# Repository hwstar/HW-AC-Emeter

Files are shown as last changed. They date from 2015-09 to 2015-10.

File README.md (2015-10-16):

**HW-AC-Emeter**
==========
This is the hardware implementation for my Atmel 90E24 power line monitor project. The Atmel 90E24 is a complete energy management solution on a chip. It allows
voltage, current, true power, apparent power, reactive power, power factor, phase angle, and line frequency to be accurately measured. Additionally it can measure
energy and with firmware, you can convert the energy pulses into kilowatt hours.

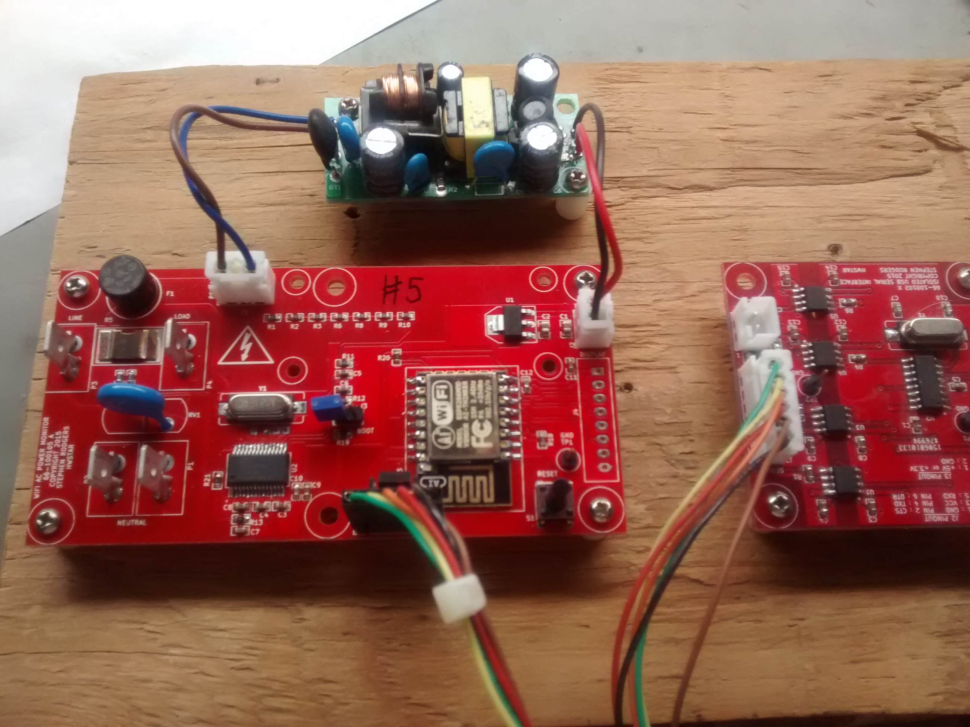
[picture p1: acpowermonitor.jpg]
ProjectPicture


**Features:**

This board contains an ESP12 module, and an Atmel 90E24 Energy monitor chip.
The board can be powered from any floating voltage source from 5V to 12V. You can optionally stuff an ESP8266 or an 8 pin connector for use with an AVR (Arduino board) or other
microprocessor which has 3 free GPIO pins. The board partially shown on the far right is used to isolate the serial data signals from the ESP8266 from mains potential to protect your computer (see NB below).
I have a separate project on Github for the [isolated USB serial port](http://github.com/hwstar/ISO-Port) 

The board is inserted into a the live (phase) and neutral leads going to a a load which runs on mains voltages.

There is a 1 milliohm current shunt on the live  side of the connections. This allows up to 24 amps to be measured.

NB: See the disclaimer below. This project is not for beginners. THE LOGIC GROUND FOR THE ATMEL 90E24 IS CONNECTED DIRECTLY TO THE AC LIVE LEAD. This means you must heed the following warnings:

1. If you want to use test equipment on this project, an isolation transformer with floating live and neutral leads is ABSOLUTELY REQUIRED if
you want to keep your scope or other grounded test equipment from being BLOWN UP. 

2. The SPI signals going to your microprocessor are not isolated from mains so your whole system will
be at line potential. Hooking these up to something which is not floating WILL cause everything connected to be DESTROYED.

3. The serial data signals on the ESP8266 version are also not isolated and are at line potential. It is absolutely required that you use an isolated USB serial interface to prevent your computer
from being BLOWN UP.

4. The power supply for Atmel 90E24 must be floating. Do not use your lab power supply or any other power supply which is not floating. Use an ungrounded 5 volt wall wart for testing.

**EDA Software**

This board was designed using KICAD. 

**Calibration**

This is the challenging part. I took some shortcuts and cut some corners. Read the 90E24 data sheet about how to go about this correctly. You need to have some way of presenting known AC loads to the unit, and correlating the results seen in the registers. 
I used a 60 watt bulb as a resistive load. This is really far from ideal as your wall socket mains voltage will vary enough to make the effort challenging and error-prone. If you have access to a stable AC power
source (K$) and precision resistive and reactive AC loads (K$), then the calibration will be much easier. The firmware will save calibration  values to non volatile memory. 

Here is my procedure for the ESP8266 version (which can probably be improved)

1. With an AC source connected no load connected, calibrate the RMS voltage by writing test values to  the Ugain register address 0x31. Example mqtt command: 
{"command":"register","addr":"31","value":"XXXX"} Where XXXX is a 4 digit hex number. Read back voltage values using the query command, and adjust Ugain until you achieve reasonable correlation. It helps to do this
when your mains voltage is the most stable (Early in the morning). The Ugain calibration values on I saw were between 0x6410 and 0x6460
2. Next, read the current with a load disconnected, and note that there is a small offset on Irms. We need to zero out this offset before we calibrate the current. 
We will need to write values to the IoffsetL register at address 0x35. The values I saw were between 0xF7E0 and 0xF8A0.
3. Connect a resistive load and an accurate current meter such as a true RMS 5 1/2 digit DMM. Adjust the value in the Igain register 0x32 so that the reading on the accurate current meter matches
the Irms value returned by the query command. The calibration values for the Igain register I saw were between 0x4A00 and  0x4AC0.
4. Make sure the PstartTH is set to its default value of 0x8BD in register 0x27. 
5. Disconnect any load. Write 0x400 into the PNolTh register at address 0x28. This prevents the unit from metering at very low currents like when there is no load connected.
6. Make sure the Lphi register at address 0x24  is set to 0. Reactive load calibration is a future improvement to this procedure. 
7. Connect a known resistive load which is switched off. Reset the kwh accumulator in the firmware using the MQTT command {"command":"resetkwh"}. Arm a stopwatch. 
Turn on the load and start the stopwatch simultaneously. Run for 6 minutes, and turn off the load. Note the kWh returned with a query command. This will be 1/10 of the desired value. If it is off, 
adjust the value in the Lgain register at address 0x23, reset the kwh accumulator, and repeat until correlation is acheived. The values I saw were between 0xF200 and 0xF300.

Note that this procedure does not encompass using small power mode as recommended in the datasheet.

There are 2 registers used for adjusting the reactive measurements. Lphi (0x24) which adjusts the phase angle and power factor, and QoffsetL (0x38) which adjusts reactive power (Qmean) offset. 
Once the calibration procedure above is completed, adjust Lphi to get the power factor to match a calibrated meter.

**Board Size**

5cm x 10cm

**Firmware**

The AVR firmware for this project can be found [here](https://github.com/hwstar/FW-AC-Emeter)
The ESP8266 firmware for this project can be found [here](https://github.com/hwstar/FW-AC-Emeter-ESP8266)

**LICENSE**

Creative Commons Attribution Share-Alike license. (CC-BY-SA)

**Disclaimer**

Build and use at your own risk. This board uses potentially lethal mains voltages. 

I will not be responsible for any damages including but not limited to: errors or omissions, loss of life, or property damage. You have been warned.

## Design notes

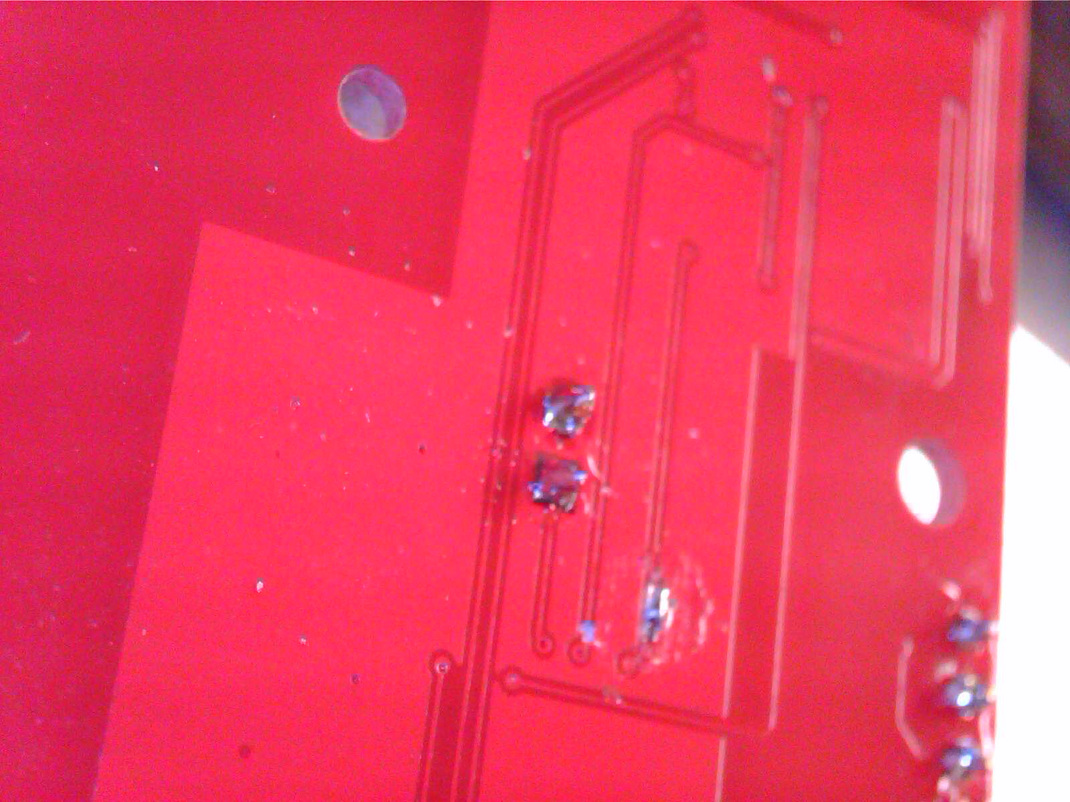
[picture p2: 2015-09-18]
x1rework1.jpg

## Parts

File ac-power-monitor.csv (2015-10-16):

Item | Part Number | Qty | Reference(s) | Title/Description | Value on Schematic | Manufacturer | Manufacturer Part Number
1 | 800004-106 | 2 | C1,C2 | CAP,0805,10u,16V,X7R | 10u | Samsung | CL21B106KOQNNNE
2 | 800002-102 | 1 | C10 | CAP,0603,1000p,50V,C0G | 1000p | Open Market | N/A
3 | 800000-104 | 4 | C7,C8,C11,C12 | CAP,0603,0.1u,25V,X7R | 0.1u | Open Market | N/A
4 | 800000-334 | 2 | C3,C4 | CAP,0603,0.33u,25V,X7R | 0.33u | TDK | CGA3E3X7R1E334K080AB
5 | 800000-333 | 2 | C5,C6 | CAP,0603,0.033u,25V,X7R | 0.033u | MURATA | GRM188R71H333KA61D
6 | 800001-105 | 1 | C9 | CAP,0603,1.0u,25V,X5R | 1u | Open Market | N/A
7 | 800125-500 | 1 | F1 | FUSE,0.5A,SLO-BLOW,8.5 X 8 MM,RADIAL | 0.5A | Littelfuse | 3720500
7 |  |  |  |  |  | Bel Fuse | MRT 500-BULK
8 | 800124-101 | 1 | J1 | CONN,HDR,SHROUDED,2PIN IN 3PIN HSG, XH | CONN2 | Open Market | N/A
9 | 800114-102 | 1 | J2 | CONN,HDR,SHROUDED,2 CKT,5MM,XH SERIES | CONN2 | JST | B2B-XH-A
10 | 800116-102 | 1 | J3 | CONN,HDR,2CKT,0.1PITCH,BERGSTRIP | CONN2 | Open Market | N/A
11 | 800114-108 | 1 | J4 | CONN,HDR,SHROUDED,8 CKT,5MM,XH SERIES | CONN8 | JST | B8B-XH-A
12 | 800116-106 | 1 | J5 | CONN,HDR,6CKT,0.1PITCH,BERGSTRIP | CONN6 | Open Market | N/A
13 | 800157-101 | 4 | P1-P4 | CONN,TERM,FASTON,MALE,PCB,0.25 TAB | FASTON_1 | Keystone Electronics | 1287-ST
14 | 800024-120 | 7 | R1-R3,R6,R8-R10 | RES,0603,120K OHM,1%,E24 | 120.0K | Open Market | N/A
15 | 800022-100 | 2 | R11,R12 | RES,0603,1.00K OHM,1% | 1.00K | Open Market | N/A
16 | 800010-100 | 1 | R13 | RES,0603,10 OHM,5% | 10 | Open Market | N/A
17 | 800011-000 | 1 | R17 | RES,0805,0 OHM, JUMPER | 0 | Open Market | N/A
18 | 800010-102 | 2 | R18,R19 | RES,0603,1K OHM,5% | 1K | Open Market | N/A
19 | 800010-103 | 2 | R20,R21 | RES,0603,10K OHM,5% | 10K | Open Market | N/A
20 | 800021-100 | 2 | R4,R7 | RES,0603,100 OHM,1% | 100.0 | Open Market | N/A
21 | 800163-101 | 1 | R5 | RES,3W,0.001 OHM, 1%,75PPM,3921 | 0.001 | Vishay | WSL39211L000FEA
22 | 800164-101 | 1 | RV1 | MOV,275V,2500APK,7.5MM LS | MOV-10D431 | Bourns | MOV-10D431K
23 | 800107-101 | 1 | S1 | SWITCH, TACT, 6MM | SW_TACT | Open Market | N/A
24 | 800130-101 | 1 | U1 | IC,VREG,3,3V,1.35A,IQ 6MA,SOT-223 | AZ1117CH-3.3TRG1 | Diodes Inc. | AZ1117CH-3.3TRG1
25 | 800159-101 | 1 | U2 | IC,ENERGY METERING,SSOP28 | 90E24PYGI | Atmel | 90E24PYGI
26 | 800106-101 | 1 | U3 | MODULE,WIFI,ESP12 | ESP8266-ESP-12 | Open Market | N/A
27 | 800108-819 | 1 | Y1 | CRYSTAL,8.192MHZ,PARALLEL,18PF,HC49US | 8.192MHz | Abracon | ABLS2-8.192MHZ-D4Y-T

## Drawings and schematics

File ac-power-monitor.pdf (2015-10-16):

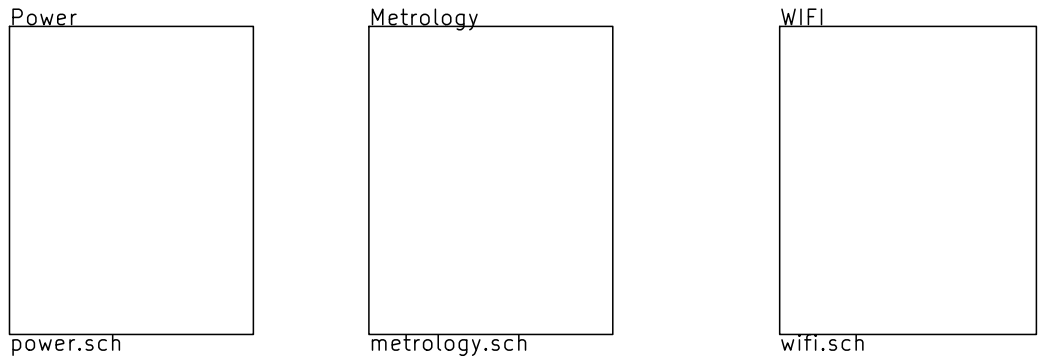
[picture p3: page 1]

File: ac-power-monitor.sch Sheet: /
Id: 1/4 Title: POWER MONITOR, AC

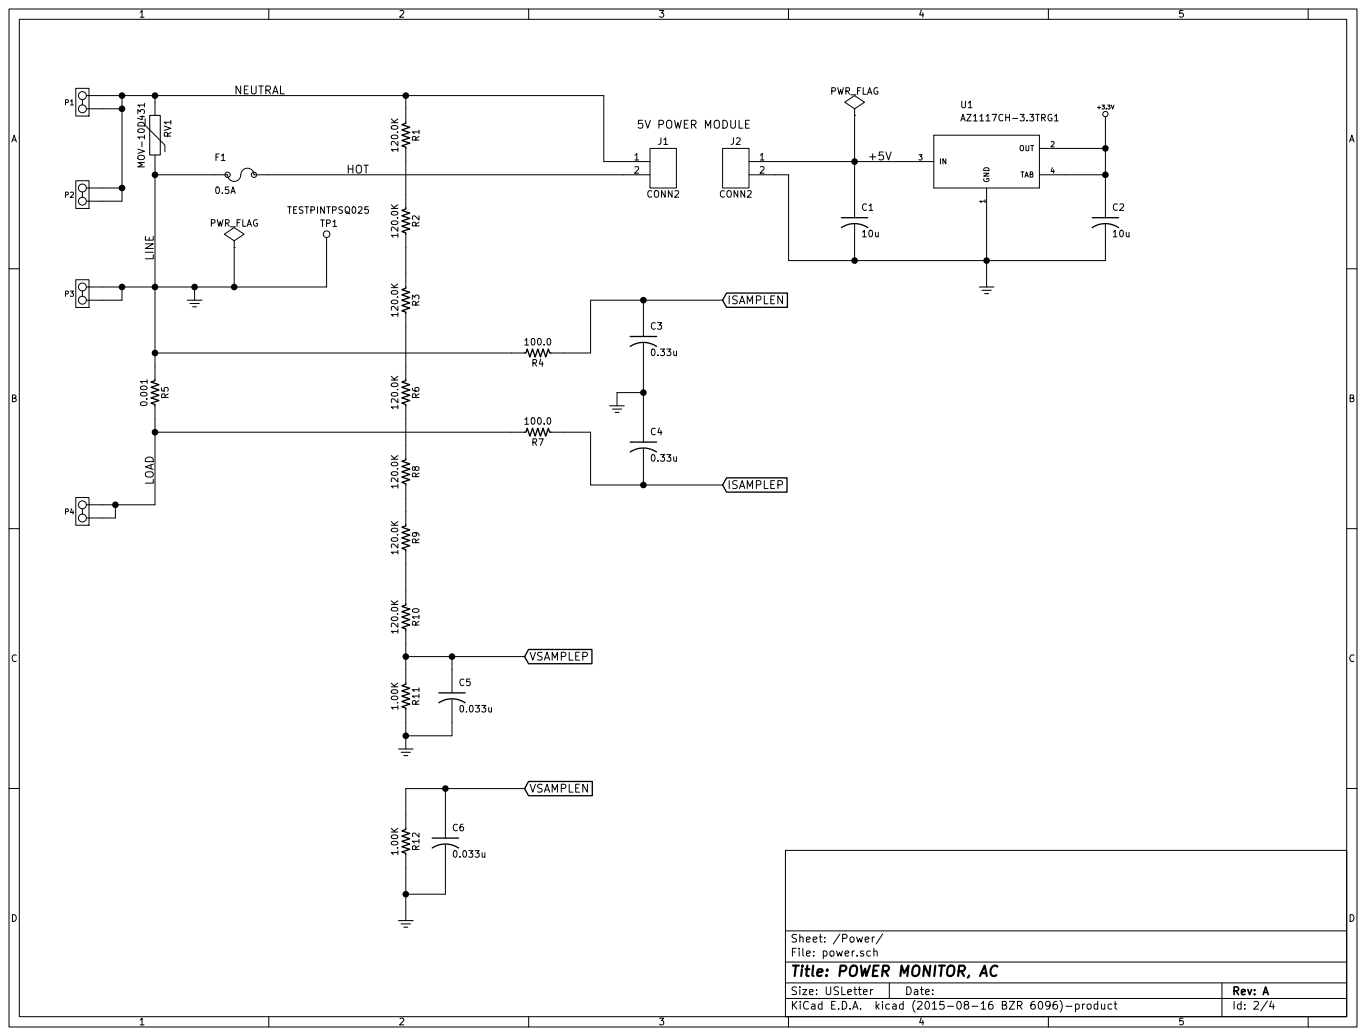
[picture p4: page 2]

Id: 2/4 Title: POWER MONITOR, AC

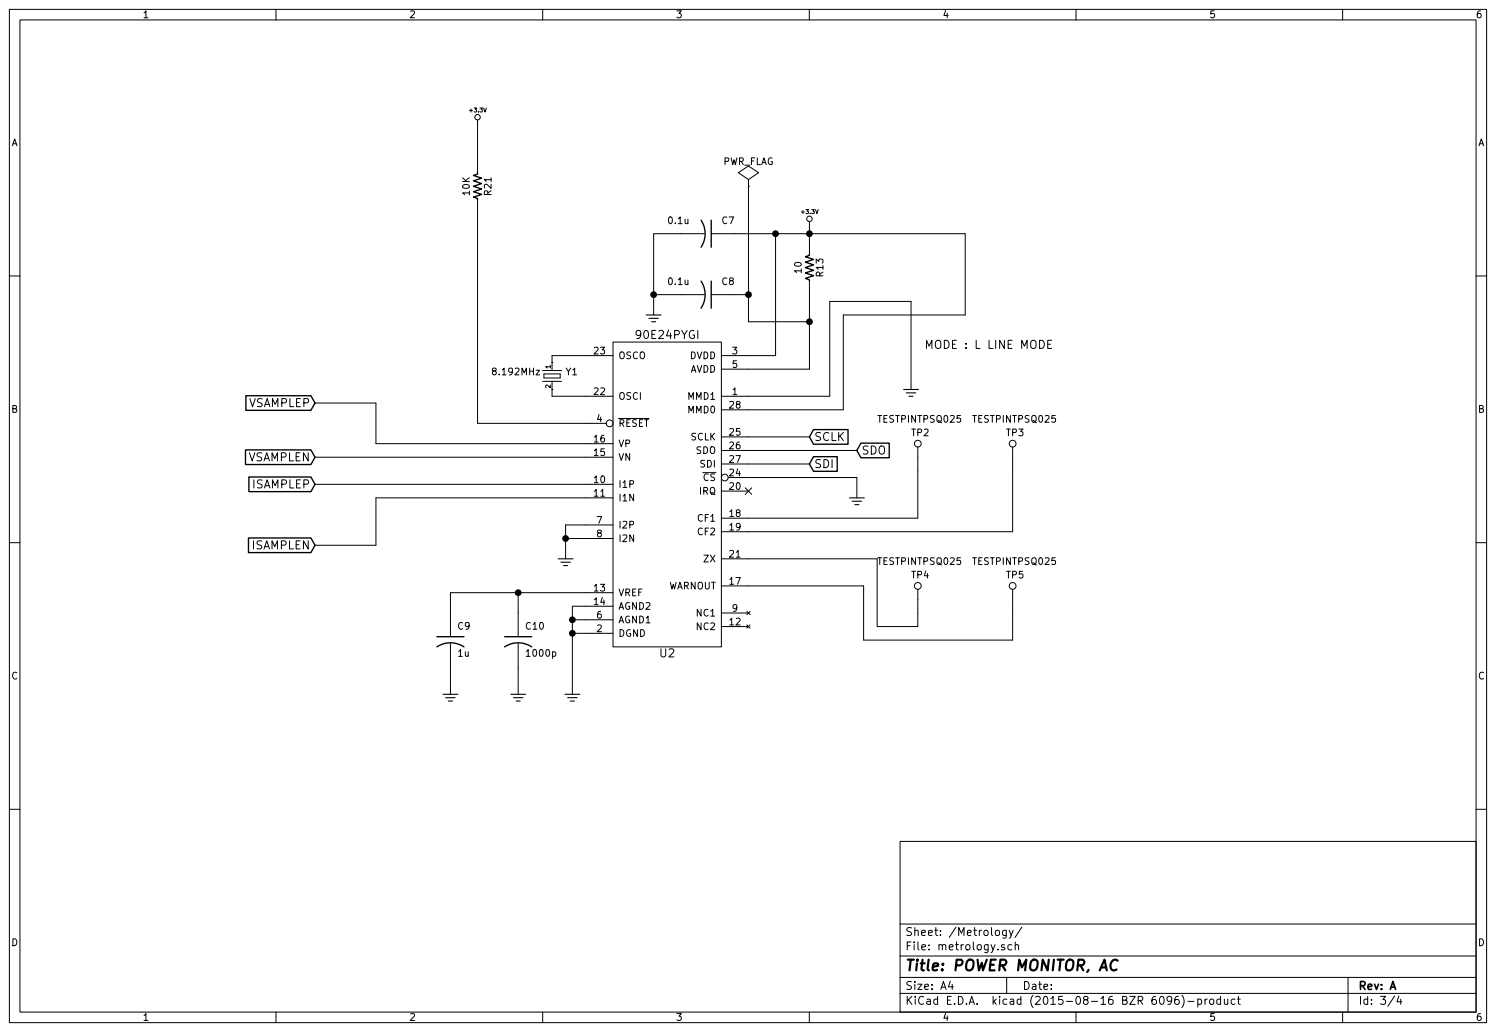
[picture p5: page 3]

File: metrology.sch
Id: 3/4 Title: POWER MONITOR, AC

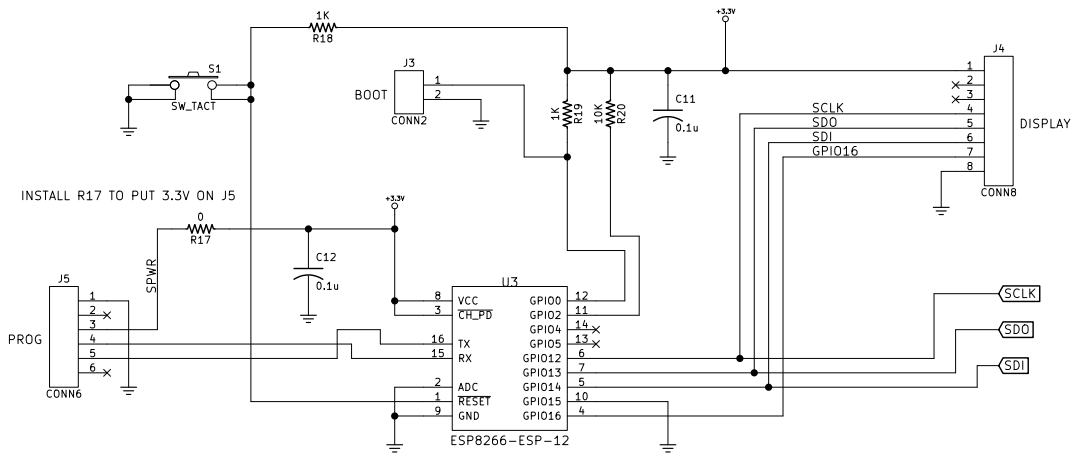
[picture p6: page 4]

SDI | 6
GPIO16 | 7

INSTALL R17 TO PUT 3.3V ON J5 SPWR

Id: 4/4 Title: POWER MONITOR, AC

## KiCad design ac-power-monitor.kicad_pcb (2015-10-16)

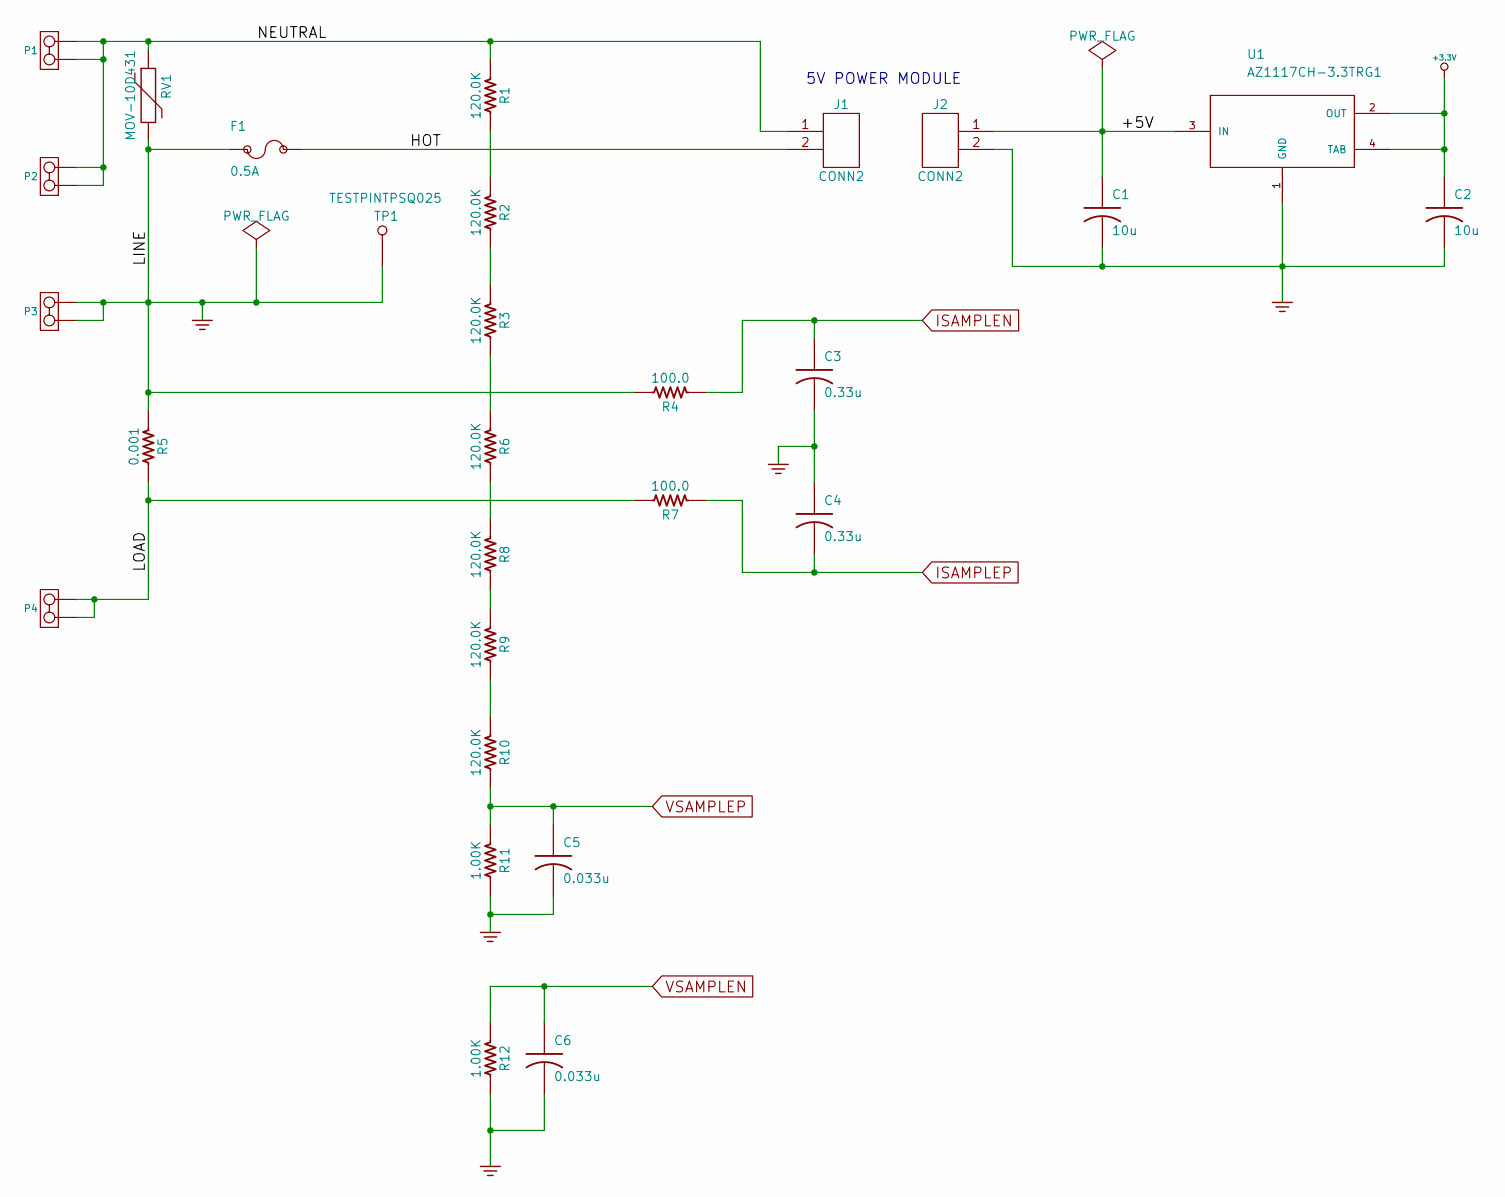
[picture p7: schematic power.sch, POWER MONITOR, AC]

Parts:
C1, C2: 10u; CC0805; PartNumber 800004-106
C3, C4: 0.33u; CC0603; PartNumber 800000-334
C5, C6: 0.033u; CC0603; PartNumber 800000-333
F1: 0.5A; BELFUSE_MRT; PartNumber 800125-500
J1: CONN2; JST_B3B_SPECIAL; PartNumber 800124-101
J2: CONN2; JST_B2B_XH_A; PartNumber 800114-102
P1, P2, P3, P4: FASTON_1; KEYSTONE_1287-ST; PartNumber 800157-101
R1, R2, R3, R6, R8, R9, R10: 120.0K; RC0603; PartNumber 800024-120
R4, R7: 100.0; RC0603; PartNumber 800021-100
R5: 0.001; RC0603; PartNumber 800163-101
R11, R12: 1.00K; RC0603; PartNumber 800022-100
RV1: MOV-10D431; VARISTOR-10D; PartNumber 800164-101
TP1: TESTPINTPSQ025; TESTPIN
U1: AZ1117CH-3.3TRG1; SOT-223-SAR; PartNumber 800130-101

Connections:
+3.3V: C2.1, U1.2 (OUT), U1.4 (TAB); also elsewhere on the board
/Power/+5V: C1.1, J2.1, U1.3 (IN)
/Power/HOT: F1.2, J1.2
/Power/LOAD: P4.1, P4.2, R5.2, R7.2
/Power/NEUTRAL: J1.1, P1.1, P1.2, P2.1, P2.2, R1.1, RV1.1
GND: C1.2, C2.2, C3.2, C4.1, C5.2, C6.2, F1.1, J2.2, P3.1, P3.2, R4.2, R5.1, R11.2, R12.2, RV1.2, TP1.1, U1.1 (GND); also elsewhere on the board
ISAMPLEN: C3.1, R4.1; also elsewhere on the board
ISAMPLEP: C4.2, R7.1; also elsewhere on the board
unnamed: R1.2, R2.1
unnamed: R2.2, R3.1
unnamed: R3.2, R6.1
unnamed: R6.2, R8.1
unnamed: R8.2, R9.1
unnamed: R9.2, R10.1
VSAMPLEN: C6.1, R12.1; also elsewhere on the board
VSAMPLEP: C5.1, R10.2, R11.1; also elsewhere on the board

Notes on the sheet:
5V POWER MODULE

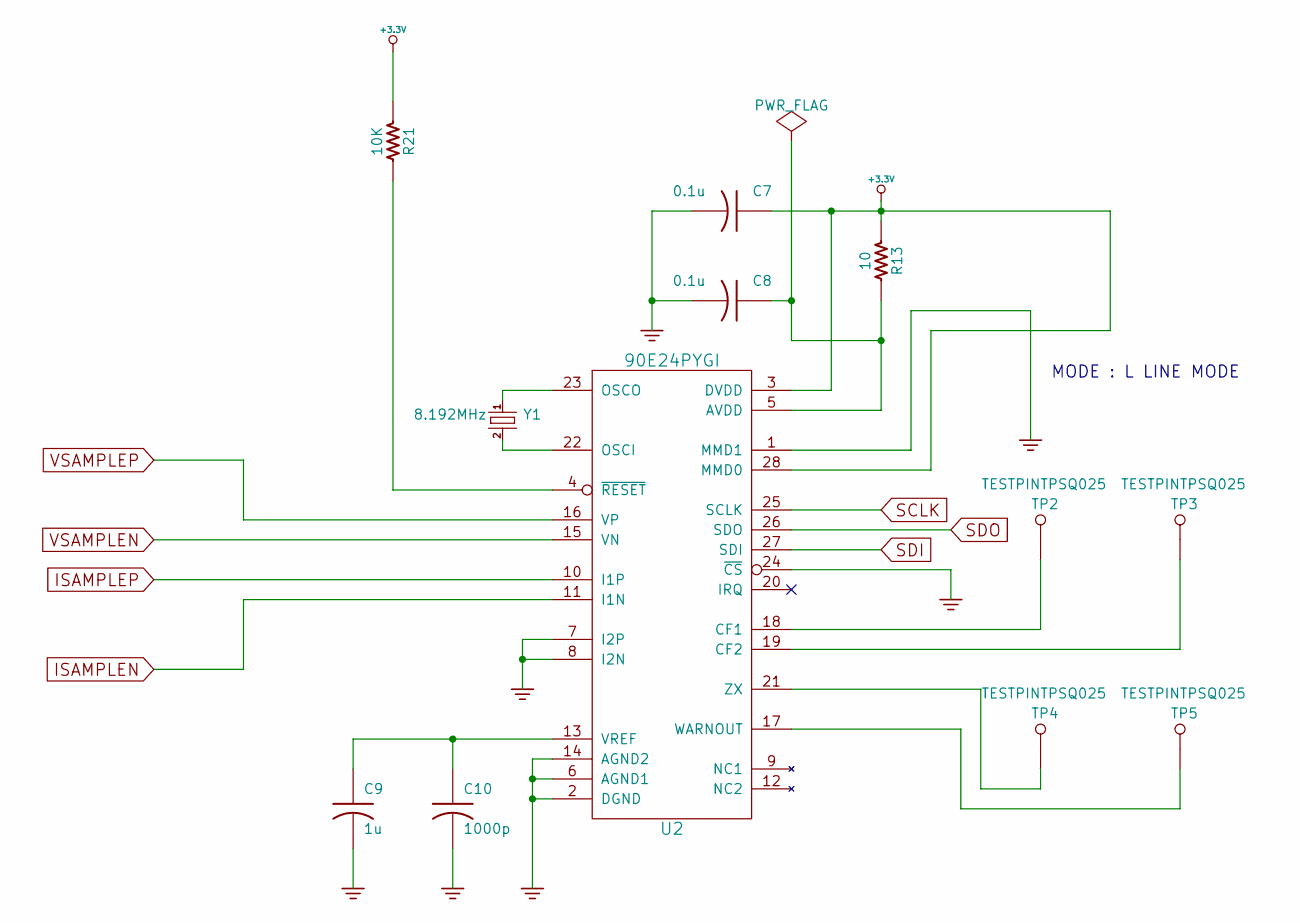
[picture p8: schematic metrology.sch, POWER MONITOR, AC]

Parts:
C7, C8: 0.1u; CC0603; PartNumber 800000-104
C9: 1u; CC0603; PartNumber 800001-105
C10: 1000p; CC0603; PartNumber 800002-102
R13: 10; RC0603; PartNumber 800010-100
R21: 10K; RC0603; PartNumber 800010-103
TP2, TP3, TP4, TP5: TESTPINTPSQ025; TESTPAD
U2: 90E24PYGI; SSOP28-SAR; PartNumber 800159-101
Y1: 8.192MHz; HC49US-SAR; PartNumber 800108-819

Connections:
+3.3V: C7.1, R13.1, R21.1, U2.3 (DVDD), U2.28 (MMD0); also elsewhere on the board
GND: C7.2, C8.2, C9.2, C10.2, U2.1 (MMD1), U2.2 (DGND), U2.6 (AGND1), U2.7 (I2P), U2.8 (I2N), U2.14 (AGND2), U2.24 (~CS); also elsewhere on the board
ISAMPLEN: U2.11 (I1N); also elsewhere on the board
ISAMPLEP: U2.10 (I1P); also elsewhere on the board
unnamed: C8.1, R13.2, U2.5 (AVDD)
unnamed: C9.1, C10.1, U2.13 (VREF)
unnamed: R21.2, U2.4 (~RESET)
unnamed: TP2.1, U2.18 (CF1)
unnamed: TP3.1, U2.19 (CF2)
unnamed: TP4.1, U2.21 (ZX)
unnamed: TP5.1, U2.17 (WARNOUT)
unnamed: U2.22 (OSCI), Y1.2
unnamed: U2.23 (OSCO), Y1.1
SCLK: U2.25 (SCLK); also elsewhere on the board
SDI: U2.27 (SDI); also elsewhere on the board
SDO: U2.26 (SDO); also elsewhere on the board
VSAMPLEN: U2.15 (VN); also elsewhere on the board
VSAMPLEP: U2.16 (VP); also elsewhere on the board

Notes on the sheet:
MODE : L LINE MODE

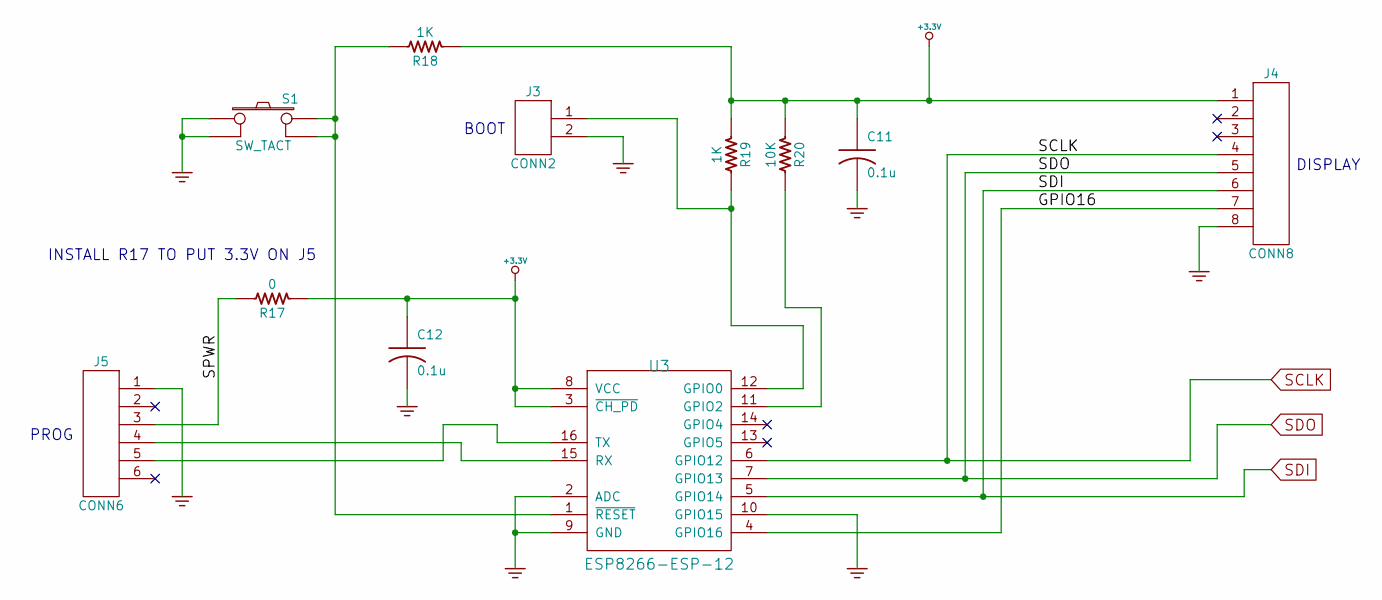
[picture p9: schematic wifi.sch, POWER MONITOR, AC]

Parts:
C11, C12: 0.1u; CC0603; PartNumber 800000-104
J3: CONN2; BERG2; PartNumber 800116-102
J4: CONN8; JST_B8B_XH_A; PartNumber 800114-108
J5: CONN6; BERG6; PartNumber 800116-106
R17: 0; RC0805; PartNumber 800011-000
R18, R19: 1K; RC0603; PartNumber 800010-102
R20: 10K; RC0603; PartNumber 800010-103
S1: SW_TACT; SW_TACT_6MM; PartNumber 800107-101
U3: ESP8266-ESP-12; ESP8266-ESP12; PartNumber 800106-101

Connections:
+3.3V: C11.1, C12.1, J4.1, R17.1, R18.1, R19.1, R20.1, U3.3 (~CH_PD), U3.8 (VCC); also elsewhere on the board
/WIFI/GPIO16: J4.7, U3.4 (GPIO16)
/WIFI/SPWR: J5.3, R17.2
GND: C11.2, C12.2, J3.2, J4.8, J5.1, S1.1, S1.2, U3.2 (ADC), U3.9 (GND), U3.10 (GPIO15); also elsewhere on the board
unnamed: J3.1, R19.2, U3.12 (GPIO0)
unnamed: J5.4, U3.15 (RX)
unnamed: J5.5, U3.16 (TX)
unnamed: R18.2, S1.3, S1.4, U3.1 (~RESET)
unnamed: R20.2, U3.11 (GPIO2)
SCLK: J4.4, U3.6 (GPIO12); also elsewhere on the board
SDI: J4.6, U3.5 (GPIO14); also elsewhere on the board
SDO: J4.5, U3.7 (GPIO13); also elsewhere on the board

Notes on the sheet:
BOOT
DISPLAY
PROG
INSTALL R17 TO PUT 3.3V ON J5

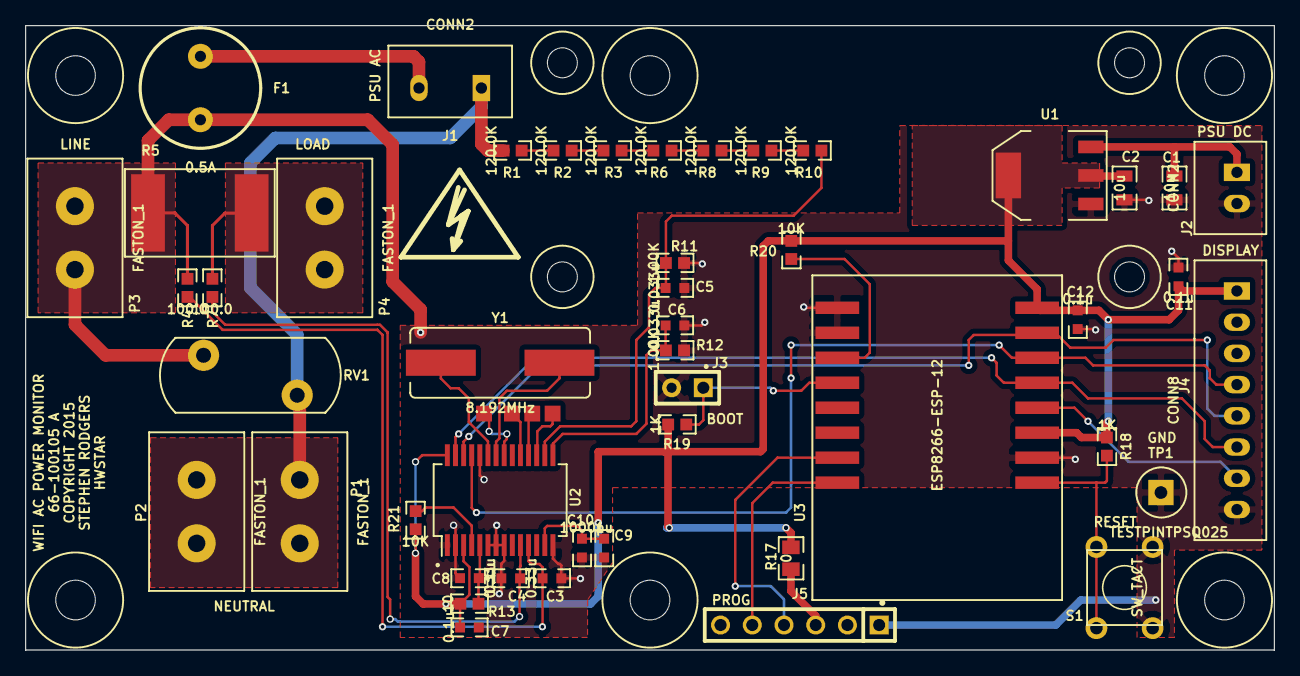
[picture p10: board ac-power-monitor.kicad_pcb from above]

Board: 2 copper layers, 100.0 x 50.0 mm, 62 parts (0 on the bottom side), 35 nets.

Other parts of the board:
MTG-HOLE-125-RING-300, MTG-HOLE-125-RING-300#2, MTG-HOLE-125-RING-300#3, MTG-HOLE-125-RING-300#4, MTG-HOLE-125-RING-300#5, MTG-HOLE-125-RING-300#6: VAL**; MTG-HOLE-125-RING-300
MTG-HOLE-M2-RING-5MM, MTG-HOLE-M2-RING-5MM#2, MTG-HOLE-M2-RING-5MM#3, MTG-HOLE-M2-RING-5MM#4: VAL**; MTG-HOLE-M2-RING-5MM
Sym: Symbol_HighVoltage_Type2_SilkTop_VerySmall

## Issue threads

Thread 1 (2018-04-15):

Board BOM?

andrew867, 2018-04-15:
Hi!

Do you happen to have a board BOM with part numbers from where you ordered the components?

Thanks,
Andrew

Vijay50, 2020-09-21:
Hi
I am also interested in the BOM , can you help?

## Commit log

2015-09-18 Initial checkin rev X1
    [ac-power-monitor.csv, ac-power-monitor.kicad_pcb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]
2015-10-04 Add calibration procedure
2015-10-13 Update README.md with reactive power info
2015-10-16 Release revision A schematic, board, and BOM. Update picture to show revision A board. Remove X1 rework instructions from README.md.
    [ac-power-monitor.csv, ac-power-monitor.kicad_pcb, ac-power-monitor.sch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]
2015-10-16 Add gerbers, remove .cmp from tracking, update pdf, net, pro.
    [ac-power-monitor-B_Cu.gbl, ac-power-monitor-B_Mask.gbs, ac-power-monitor-B_SilkS.gbo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]
2015-10-16 Update revision letters on schematic pages
    [metrology.sch, power.sch, wifi.sch]

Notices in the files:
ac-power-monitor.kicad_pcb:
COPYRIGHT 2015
